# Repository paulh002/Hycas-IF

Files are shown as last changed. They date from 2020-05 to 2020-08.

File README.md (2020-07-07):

# Hycas-IF
Hycas IF amplifier inclusive product detector, s-meter and audio amp

This is my take on the well know W7ZOI hycas if amplifier. I made several versions one through the whole and after that SMD using mostly 1206 SMD components. Check the footprints for details because sometime the kicad libraries are not very consistant creating issues with ordering the wrong components (The diodes were 323 instead of DO-23 so needed to order again).
I included the s-meter extension which works very well. There are some resistors which may need some tuning depending on how much gain you want to achieve (I changed R17 to 1K instead of 3.3k to reduce the hiss, also R25 270 Ohm I needed to reduce to 47 Ohm the get the AVC responding faster in the shared kicad pcb layout it is now a potmeter)
For audio amplifier it uses a TDA 2003 which is driven by a small pre-amp. The input of the pre-amp is shortend with 100NF to supress HF into the audio stage.

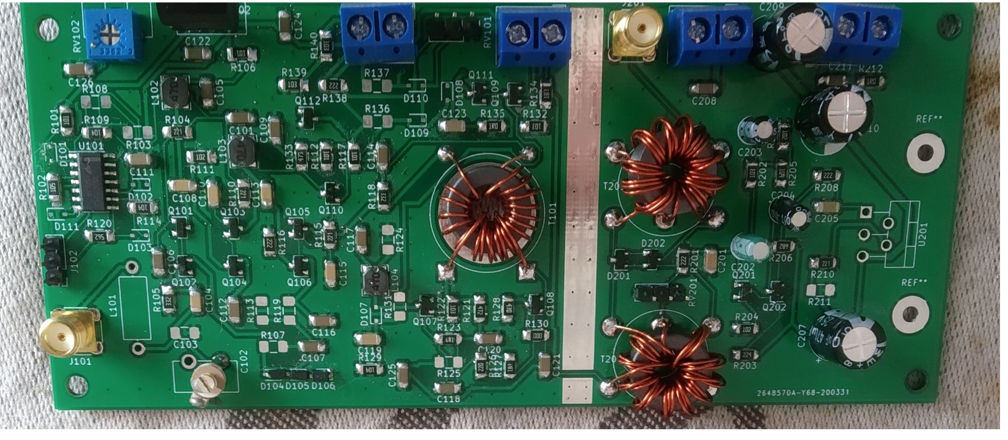
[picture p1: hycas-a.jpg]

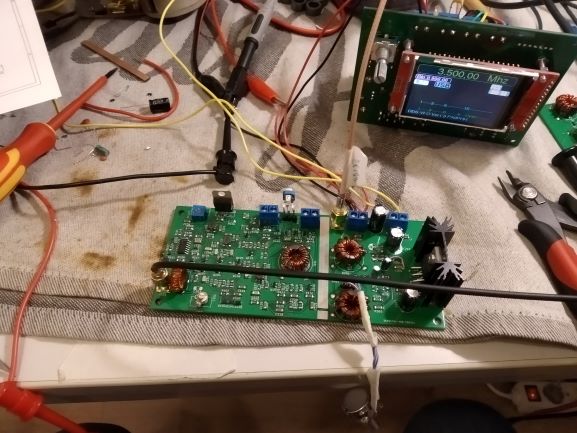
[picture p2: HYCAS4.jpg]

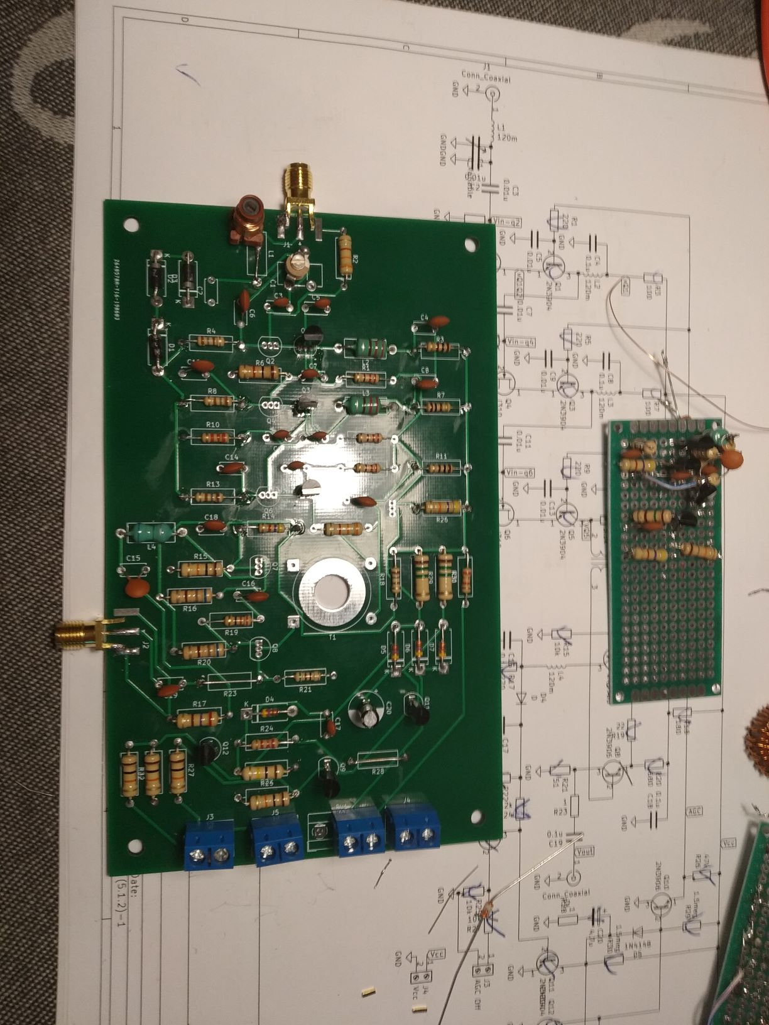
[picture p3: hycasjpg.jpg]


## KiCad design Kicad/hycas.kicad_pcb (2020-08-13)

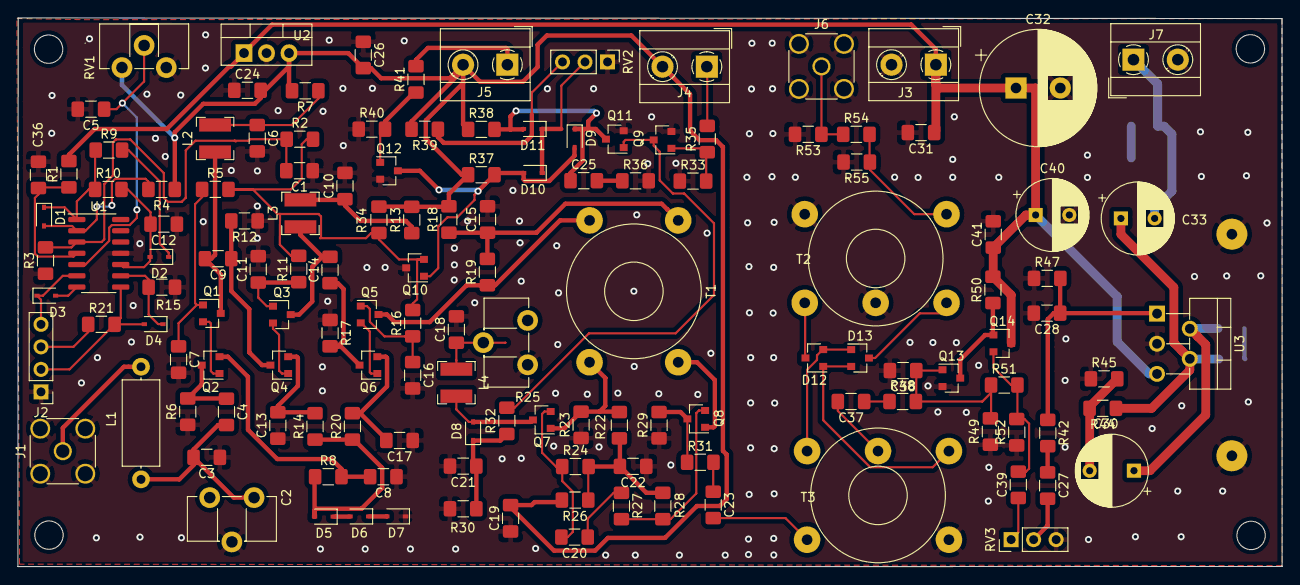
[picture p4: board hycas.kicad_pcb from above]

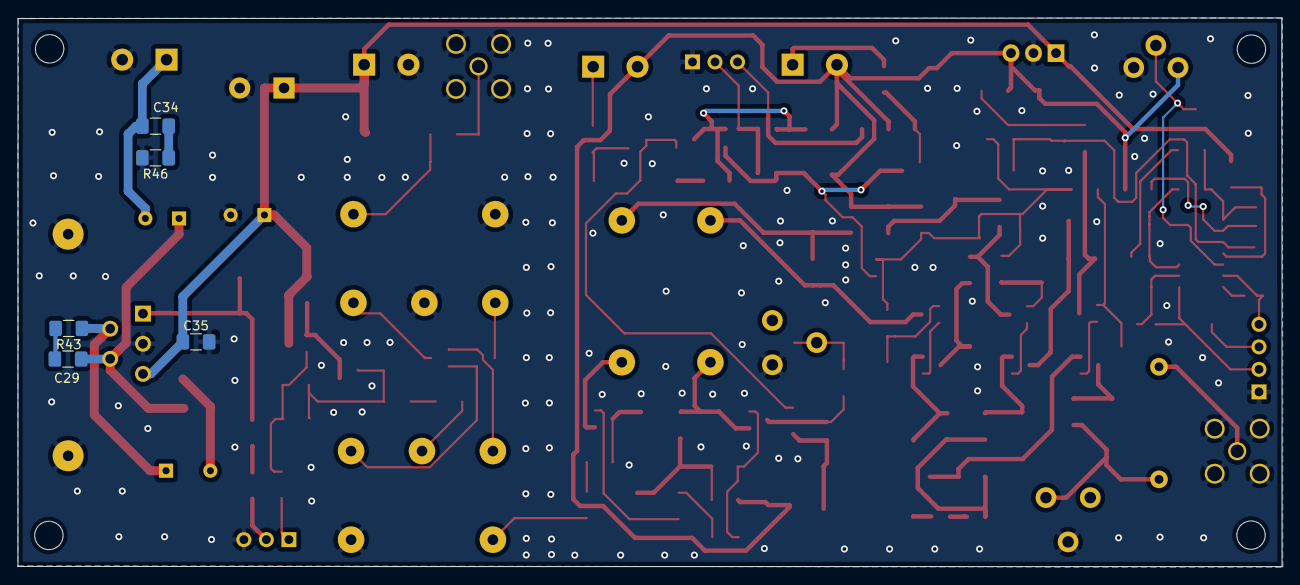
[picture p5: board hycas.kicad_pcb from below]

Board: 2 copper layers, 142.6 x 61.9 mm, 149 parts (5 on the bottom side), 82 nets.

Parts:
 : SolderWirePad_1x01_Drill1.2mm
 #2: SolderWirePad_1x01_Drill1.2mm
 #3,  #4,  #5,  #6: MountingHole_3.2mm_M3
C1, C5, C6, C8, C10, C13, C15, C17, C18, C19, C20, C22, C23, C26, C34, C36: 0.1u; C_1206_3216Metric_Pad1.42x1.75mm_HandSolder
C2: C_Variable; Potentiometer_ACP_CA9-H5_Horizontal
C3, C4, C7, C9, C11, C14, C16, C21: 0.01u; C_1206_3216Metric_Pad1.42x1.75mm_HandSolder
C12, C25: 4.7u; C_1206_3216Metric_Pad1.42x1.75mm_HandSolder
C24: 10u; C_1206_3216Metric_Pad1.42x1.75mm_HandSolder
C27, C37, C39: 1u; C_1206_3216Metric_Pad1.42x1.75mm_HandSolder
C28: 820p; C_1206_3216Metric_Pad1.42x1.75mm_HandSolder
C29: 39nf; C_1206_3216Metric_Pad1.42x1.75mm_HandSolder
C30: 470u; CP_Radial_D8.0mm_P5.00mm
C31, C35, C41: 100nf; C_1206_3216Metric_Pad1.42x1.75mm_HandSolder
C32: 2200u; CP_Radial_D13.0mm_P5.00mm
C33, C40: 470u; CP_Radial_D8.0mm_P3.80mm
C38: 100n; C_1206_3216Metric_Pad1.42x1.75mm_HandSolder
D1, D2, D3, D4, D5, D6, D7, D8: D; D_SOD-323
D9, D10, D11: 1N4148; D_SOD-323
D12, D13: BAT54S; SOT-23
J1: Conn_Coaxial; SMA_Amphenol_132134_Vertical
J2: S-Meter; PinHeader_1x04_P2.54mm_Vertical
J3: Vcc; TerminalBlock_MetzConnect_Type055_RT01502HDWU_1x02_P5.00mm_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
J4: AGC Off; TerminalBlock_MetzConnect_Type055_RT01502HDWU_1x02_P5.00mm_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
J5: Mute; TerminalBlock_MetzConnect_Type055_RT01502HDWU_1x02_P5.00mm_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
J6: BFO; SMA_Amphenol_132134_Vertical
J7: Speaker; TerminalBlock_MetzConnect_Type055_RT01502HDWU_1x02_P5.00mm_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
L1: 120m; L_Axial_L9.5mm_D4.0mm_P12.70mm_Horizontal_Fastron_SMCC
L2, L3, L4: 120m; L_Bourns-SRN4018
Q1, Q3, Q5, Q9, Q11, Q12: 2N3904; SOT-23
Q2, Q4, Q6: J310; SOT-23
Q7, Q8, Q10: 2N3906; SOT-23
Q13, Q14: 2N3904_SOT23; SOT-23
R1, R7, R13, R18: 100; R_1206_3216Metric_Pad1.42x1.75mm_HandSolder
R2, R23, R33, R35, R40, R41: 10k; R_1206_3216Metric_Pad1.42x1.75mm_HandSolder
R3: 1meg; R_1206_3216Metric_Pad1.42x1.75mm_HandSolder
R4: 22k; R_1206_3216Metric_Pad1.42x1.75mm_HandSolder
R5, R11, R16, R44: 220; R_1206_3216Metric_Pad1.42x1.75mm_HandSolder
R6: 3k; R_1206_3216Metric_Pad1.42x1.75mm_HandSolder
R8, R14, R20, R26: 180; R_1206_3216Metric_Pad1.42x1.75mm_HandSolder
R9, R22: 4.7k; R_1206_3216Metric_Pad1.42x1.75mm_HandSolder
R10, R15, R30, R47: 100k; R_1206_3216Metric_Pad1.42x1.75mm_HandSolder
R12, R17, R48, R49, R50: 1k; R_1206_3216Metric_Pad1.42x1.75mm_HandSolder
R19: 3.3k; R_1206_3216Metric_Pad1.42x1.75mm_HandSolder
R21: 5.1k; R_1206_3216Metric_Pad1.42x1.75mm_HandSolder
R24, R28: 680; R_1206_3216Metric_Pad1.42x1.75mm_HandSolder
R25: 270; Potentiometer_ACP_CA9-H5_Horizontal
R27: 22; R_1206_3216Metric_Pad1.42x1.75mm_HandSolder
R29: 51; R_1206_3216Metric_Pad1.42x1.75mm_HandSolder
R31, R36, R46: 1; R_1206_3216Metric_Pad1.42x1.75mm_HandSolder
R32, R39, R42: 2.2k; R_1206_3216Metric_Pad1.42x1.75mm_HandSolder
R34: 47k; R_1206_3216Metric_Pad1.42x1.75mm_HandSolder
R37, R38: 1.5meg; R_1206_3216Metric_Pad1.42x1.75mm_HandSolder
R43: 39; R_1206_3216Metric_Pad1.42x1.75mm_HandSolder
R45: 2.2; R_1206_3216Metric_Pad1.42x1.75mm_HandSolder
R51: 5k; R_1206_3216Metric_Pad1.42x1.75mm_HandSolder
R52: 500; R_1206_3216Metric_Pad1.42x1.75mm_HandSolder
R53, R55: 150; R_1206_3216Metric_Pad1.42x1.75mm_HandSolder
R54: 33; R_1206_3216Metric_Pad1.42x1.75mm_HandSolder
RV1: R_POT; Potentiometer_ACP_CA9-H2,5_Horizontal
RV2: 5k; PinHeader_1x03_P2.54mm_Vertical
RV3: 10k; PinHeader_1x03_P2.54mm_Vertical
T1: 16T 4T FB-43-2401; Transformer_Toroid_Horizontal_D14.0mm_Amidon-T50
T2, T3: T50-6; Transformer_Toroid_Horizontal_3S_D14.0mm_Amidon-T50
U1: LM324; SOIC-14_3.9x8.7mm_P1.27mm
U2: L7809; TO-220-3_Vertical
U3: TDA2003; TO-220-5_P3.4x3.7mm_StaggerOdd_Lead3.8mm_Vertical

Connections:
AGC: Q10.2, R2.2, R5.2, R11.2, R16.2, R34.2
GND: .1, #2.1, C1.1, C2.2, C3.1, C5.2, C6.2, C7.2, C8.1, C10.2, C11.2, C12.1, C13.1, C15.2, C16.2, C17.1, C18.2, C19.1, C21.2, C22.1, C24.1, C26.1, C28.2, C31.2, C32.2, C35.2, C36.1, C38.2, C40.2, C41.2, D7.1, J1.2, J2.1, J3.2, J6.2, J7.2, Q9.2, Q10.3, Q11.2, Q12.2, Q13.2, R3.1, R6.1, R12.1, R15.2, R17.1, R23.1, R25.1, R29.1, R30.1, R33.1, R36.2, R40.1, R45.1, R46.2, R47.1, R49.1, R52.1, R53.2, R55.2, RV1.3, RV2.1, RV3.3, T2.2, T2.4, T3.2, U1.11, U2.2, U3.3
IF: C23.2, T3.1
Mute: J5.1, R41.2
unnamed: C1.2, R2.1, R3.2, U1.3
unnamed: C2.1, C3.2, C4.2, L1.2
unnamed: C5.1, RV1.2, U1.5
unnamed: C7.1, Q1.1, R5.1
unnamed: C9.2, L2.2, Q1.3
unnamed: C10.1, L3.1, R13.1
unnamed: C11.1, Q3.1, R11.1
unnamed: C12.2, D2.2, R10.2, U1.10
unnamed: C13.2, Q4.2, R14.2
unnamed: C14.2, L3.2, Q3.3
unnamed: C15.1, R18.1, R19.2, T1.1
unnamed: C16.1, Q5.1, R16.1
unnamed: C17.2, Q6.2, R20.2
unnamed: C18.1, L4.2, R25.2
unnamed: C20.1, R27.1
unnamed: C20.2, Q7.2, R24.1
unnamed: C21.1, D8.1, R30.2, R32.1
unnamed: C22.2, R22.2, R24.2, R26.1, R28.2
unnamed: C23.1, R31.2
unnamed: C25.1, D9.1, D11.2, Q11.3, R38.2
unnamed: C25.2, R36.1
unnamed: C27.1, R42.2
unnamed: C27.2, RV3.2
unnamed: C28.1, R42.1, R47.2, U3.1
unnamed: C29.1, R43.2
unnamed: C29.2, C33.1, R44.1, U3.4
unnamed: C30.1, R43.1, U3.2
unnamed: C30.2, R44.2, R45.2
unnamed: C33.2, C34.2, J7.1
unnamed: C34.1, R46.1
unnamed: C36.2, R1.1, U1.4
unnamed: C37.1, R48.1
unnamed: C37.2, T3.4
unnamed: C38.1, Q13.1, R48.2, R49.2, R51.1
unnamed: C39.1, RV3.1
unnamed: C39.2, Q14.2, R51.2, R52.2
unnamed: D1.1, R9.1, R10.1, U1.1
unnamed: D1.2, R4.2, U1.2
unnamed: D2.1, R9.2
unnamed: D3.1, J2.4, U1.6
unnamed: D3.2, U1.7
unnamed: D4.1, R15.1, U1.9
unnamed: D4.2, J2.2, R21.2, U1.8
unnamed: D5.1, D6.2
unnamed: D6.1, D7.2
unnamed: D8.2, L4.1, Q7.3
unnamed: D10.1, D11.1, RV2.2
unnamed: D9.2, D10.2, Q10.1, Q12.3, R37.2
unnamed: D12.1, D13.2, T3.5
unnamed: D12.2, D13.1, T3.3
unnamed: D12.3, T2.5
unnamed: D13.3, T2.3
unnamed: J1.1, L1.1
unnamed: J2.3, R21.1
unnamed: J4.1, R35.2
unnamed: J6.1, R53.1, R54.1
unnamed: Q3.2, Q4.1
unnamed: Q5.2, Q6.1
unnamed: Q8.1, T1.3
unnamed: Q8.2, R27.2, R28.1
unnamed: Q8.3, R29.2, R31.1
unnamed: Q9.1, R33.2, R35.1
unnamed: Q9.3, Q11.1, R32.2
unnamed: Q12.1, R40.2, R41.1
unnamed: Q13.3, Q14.1, R50.1
unnamed: R39.1, RV2.3
unnamed: R54.2, R55.1, T2.1
V12v: C31.1, C32.1, C35.1, C40.1, C41.1, J3.1, Q14.3, R1.2, R50.2, U2.1, U3.5
VQ5: Q5.3, R19.1, T1.2
VSource: D5.2, R8.1, R14.1, R20.1
Vcc: C19.2, C24.2, C26.2, J4.2, J5.2, R4.1, R7.2, R13.2, R18.2, R26.2, R34.1, R37.1, R38.1, R39.2, RV1.1, U2.3
Vin2: R22.1, R23.2, T1.4
Vin-q2: C4.1, Q2.3, R6.2
Vin-q4: C9.1, Q4.3, R12.2
Vin-q6: C14.1, Q6.3, R17.2
vQ1: C6.1, L2.1, R7.1
vQ1Q2: Q1.2, Q2.1
vsQ1: C8.2, Q2.2, R8.2
